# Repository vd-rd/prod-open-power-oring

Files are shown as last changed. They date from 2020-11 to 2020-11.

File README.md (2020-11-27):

# PowerPath controller with HotSwap protection

This module is designed to provide redundant power supply for power rails between 5-36V. Depending on the components that are populated on the board it can deliver up to 40A of current. The module can be used in a standalone configuration (switches are provided to select desired functionality) or can be controlled using the 2.54 pin header.

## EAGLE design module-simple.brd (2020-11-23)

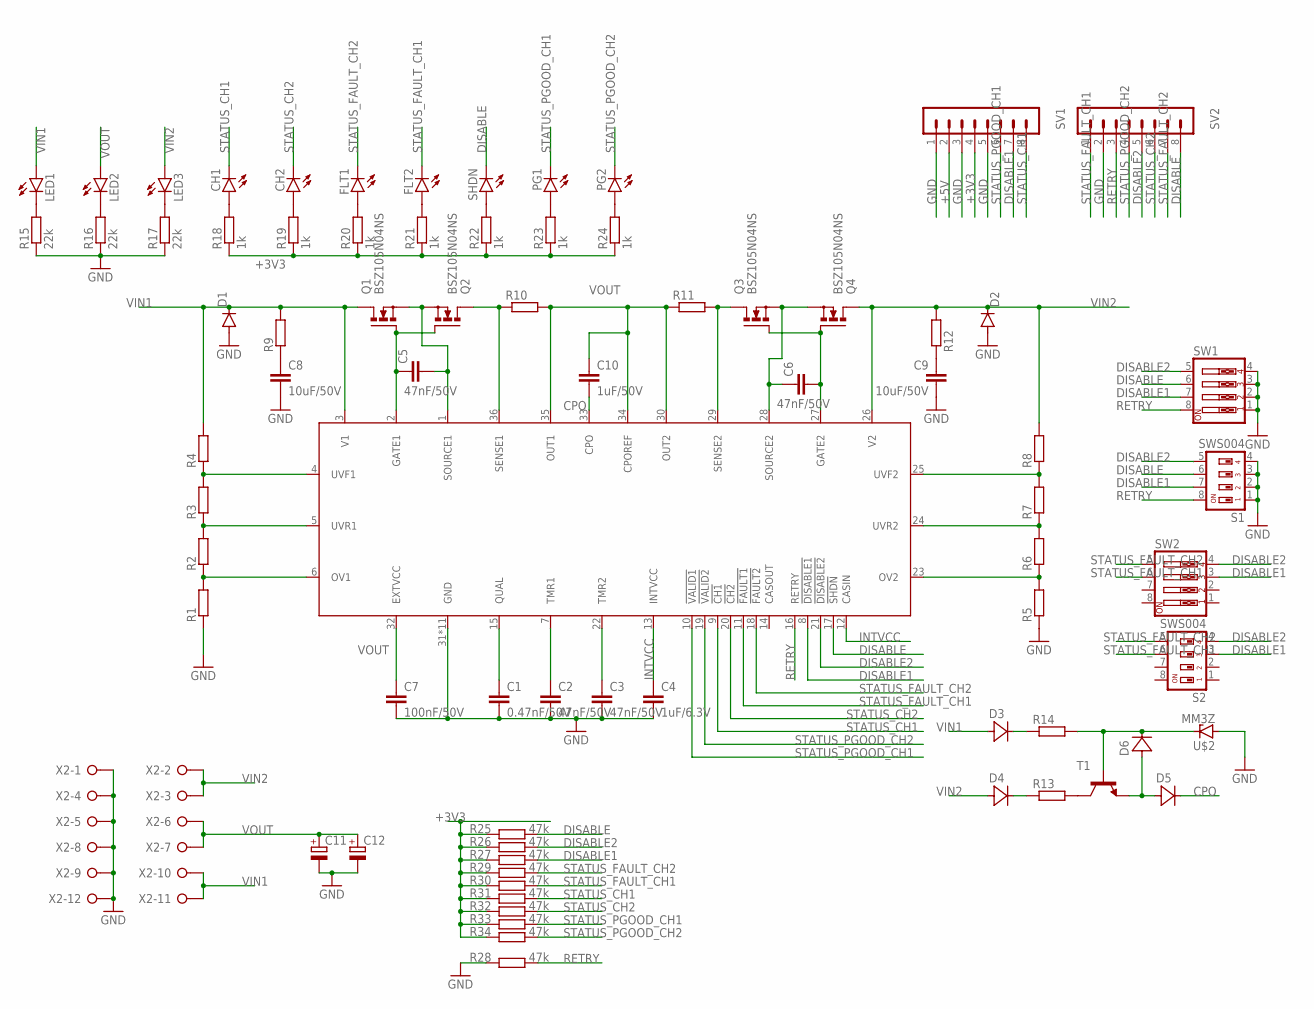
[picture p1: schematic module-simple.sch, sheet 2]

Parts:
C1: 0.47nF/50V; C0603
C2, C3, C5, C6: 47nF/50V; C0603
C4: 1uF/6.3V; C0603
C7: 100nF/50V; C0603
C8, C9: 10uF/50V; C1206
C10: 1uF/50V; C0805
C11, C12: CPOL-EU140CLH-1010; 140CLH-1010
CH1, CH2: LEDCHIP-LED0603; CHIP-LED0603
D1, D2: DIODE-DO214AC; DO214AC
D3, D4, D5, D6: 1N4148WS; SOD323
FLT1, FLT2: LEDCHIP-LED0603; CHIP-LED0603
LED1, LED2, LED3: LEDCHIP-LED0603; CHIP-LED0603
PG1, PG2: LEDCHIP-LED0603; CHIP-LED0603
Q1, Q2, Q3, Q4: BSZ105N04NS; PG-TDSON-8
R1, R2, R3, R4, R5, R6, R7, R8, R9, R12, R13, R14: R-EU_R0603; R0603
R10, R11: R-EU_R2512; R2512
R15, R16, R17: 22k; R0603
R18, R19, R20, R21, R22, R23, R24: 1k; R0603
R25, R26, R27, R28, R29, R30, R31, R32, R33, R34: 47k; R0603
S1, S2: SWS004; SMS-004
SHDN: LEDCHIP-LED0603; CHIP-LED0603
SV1, SV2: MA08-1
SW1, SW2: SW_DIP-4; EDG-04
T1: MMBT2222ALT1-NPN-SOT23-BEC; SOT23-BEC
U$1: LTC4421; QFN50P600X500X75-37T460X360N
U$2: MM3Z; SOD323
X2: W237-12P

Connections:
+3V3: R18.1, R19.1, R20.1, R21.1, R22.1, R23.1, R24.1, R25.1, R26.1, R27.1, R29.1, R30.1, R31.1, R32.1, R33.1, R34.1, SV1.4; also elsewhere on the board
+5V: SV1.2; also elsewhere on the board
CPO: C10.2, D5.K (C), U$1.33 (CPO)
DISABLE: R25.2, S1.6, SHDN.C, SV2.8, SW1.6, U$1.17 (!SHDN)
DISABLE1: R27.2, S1.7, S2.3, SV1.7, SW1.7, SW2.3, U$1.8 (!DISABLE1)
DISABLE2: R26.2, S1.5, S2.4, SV2.5, SW1.5, SW2.4, U$1.21 (!DISABLE2)
GND: C1.2, C2.2, C3.2, C4.2, C7.2, C8.2, C9.2, C11.-, C12.-, D1.A, D2.A, R1.1, R5.1, R15.1, R16.1, R17.1, R28.1, S1.1, S1.2, S1.3, S1.4, SV1.1, SV1.3, SV1.5, SV2.2, SW1.1, SW1.2, SW1.3, SW1.4, U$1.31 (GND), U$1.37 (GND), U$1.P$1 (GND), U$1.P$2 (GND), U$1.P$3 (GND), U$1.P$4 (GND), U$1.P$5 (GND), U$1.P$6 (GND), U$1.P$7 (GND), U$1.P$8 (GND), U$1.P$9 (GND), U$2.A, X2.1, X2.4, X2.5, X2.8, X2.9, X2.12; also elsewhere on the board
INTVCC: C4.1, U$1.12 (CASIN), U$1.13 (INTVCC)
unnamed: R1.2, R2.1, U$1.6 (OV1)
unnamed: R2.2, R3.1, U$1.5 (UVR1)
unnamed: R3.2, R4.1, U$1.4 (UVF1)
unnamed: R5.2, R6.1, U$1.23 (OV2)
unnamed: R6.2, R7.1, U$1.24 (UVR2)
unnamed: R7.2, R8.1, U$1.25 (UVF2)
unnamed: C5.1, Q1.4 (G), Q2.4 (G), U$1.2 (GATE1)
unnamed: C5.2, Q1.1 (S), Q1.2 (S), Q1.3 (S), Q2.1 (S), Q2.2 (S), Q2.3 (S), U$1.1 (SOURCE1)
unnamed: Q2.5 (D), Q2.6 (D), Q2.7 (D), Q2.8 (D), Q2.TH (D), R10.1, U$1.36 (SENSE1)
unnamed: C8.1, R9.1
unnamed: C9.1, R12.1
unnamed: D4.K (C), R13.1
unnamed: C1.1, U$1.15 (QUAL)
unnamed: Q3.5 (D), Q3.6 (D), Q3.7 (D), Q3.8 (D), Q3.TH (D), R11.2, U$1.29 (SENSE2)
unnamed: C6.2, Q3.4 (G), Q4.4 (G), U$1.27 (GATE2)
unnamed: C6.1, Q3.1 (S), Q3.2 (S), Q3.3 (S), Q4.1 (S), Q4.2 (S), Q4.3 (S), U$1.28 (SOURCE2)
unnamed: D3.K (C), R14.1
unnamed: C2.1, U$1.7 (TMR1)
unnamed: C3.1, U$1.22 (TMR2)
unnamed: R13.2, T1.C
unnamed: D6.K (C), R14.2, T1.B, U$2.K
unnamed: D5.A, D6.A, T1.E
unnamed: LED1.C, R15.2
unnamed: LED2.C, R16.2
unnamed: LED3.C, R17.2
unnamed: CH1.A, R18.2
unnamed: CH2.A, R19.2
unnamed: FLT1.A, R20.2
unnamed: FLT2.A, R21.2
unnamed: R22.2, SHDN.A
unnamed: PG1.A, R23.2
unnamed: PG2.A, R24.2
RETRY: R28.2, S1.8, SV2.3, SW1.8, U$1.16 (RETRY)
STATUS_CH1: CH1.C, R31.2, SV1.8, U$1.9 (!CH1)
STATUS_CH2: CH2.C, R32.2, SV2.6, U$1.20 (!CH2)
STATUS_FAULT_CH1: FLT2.C, R30.2, S2.6, SV2.1, SW2.6, U$1.11 (!FAULT1)
STATUS_FAULT_CH2: FLT1.C, R29.2, S2.5, SV2.7, SW2.5, U$1.18 (!FAULT2)
STATUS_PGOOD_CH1: PG1.C, R33.2, SV1.6, U$1.10 (!VALID1)
STATUS_PGOOD_CH2: PG2.C, R34.2, SV2.4, U$1.19 (!VALID2)
VIN1: D1.C, D3.A, LED1.A, Q1.5 (D), Q1.6 (D), Q1.7 (D), Q1.8 (D), Q1.TH (D), R4.2, R9.2, U$1.3 (V1), X2.10, X2.11
VIN2: D2.C, D4.A, LED3.A, Q4.5 (D), Q4.6 (D), Q4.7 (D), Q4.8 (D), Q4.TH (D), R8.2, R12.2, U$1.26 (V2), X2.2, X2.3
VOUT: C7.1, C10.1, C11.+, C12.+, LED2.A, R10.2, R11.1, U$1.30 (OUT2), U$1.32 (EXTVCC), U$1.34 (CPOREF), U$1.35 (OUT1), X2.6, X2.7; also elsewhere on the board

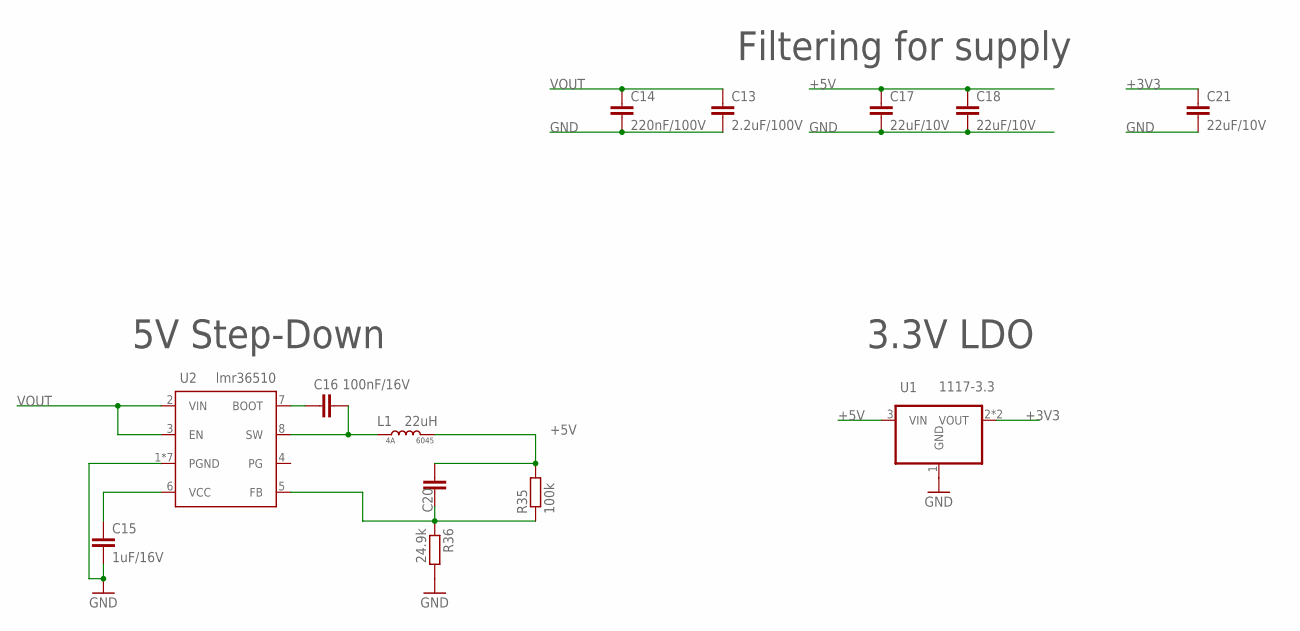
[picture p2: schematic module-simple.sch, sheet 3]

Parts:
C13: 2.2uF/100V; C1210
C14: 220nF/100V; C1210
C15: 1uF/16V; C0805
C16: 100nF/16V; C0805
C17, C18, C21: 22uF/10V; C1210
C20: C-EUC0603; C0603
L1: 22uH; DJNR6045
R35: 100k; R0603
R36: 24.9k; R0603
U1: 1117-3.3; SOT230P700X180-4
U2: lmr36510; SOIC127P600X170-9T240X310N

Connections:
+3V3: C21.1, U1.2 (VOUT), U1.4 (VOUT); also elsewhere on the board
+5V: C17.1, C18.1, C20.2, L1.P$2 (2), R35.2, U1.3 (VIN); also elsewhere on the board
GND: C13.2, C14.2, C15.2, C17.2, C18.2, C21.2, R36.2, U1.1 (GND), U2.1 (PGND), U2.9 (PGND), U2.P$1 (PGND), U2.P$2 (PGND), U2.P$3 (PGND), U2.P$4 (PGND), U2.P$5 (PGND); also elsewhere on the board
unnamed: C15.1, U2.6 (VCC)
unnamed: C16.1, U2.7 (BOOT)
unnamed: C16.2, L1.P$1 (1), U2.8 (SW)
unnamed: C20.1, R35.1, R36.1, U2.5 (FB)
VOUT: C13.1, C14.1, U2.2 (VIN), U2.3 (EN); also elsewhere on the board

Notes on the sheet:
5V Step-Down
3.3V LDO
Filtering for supply

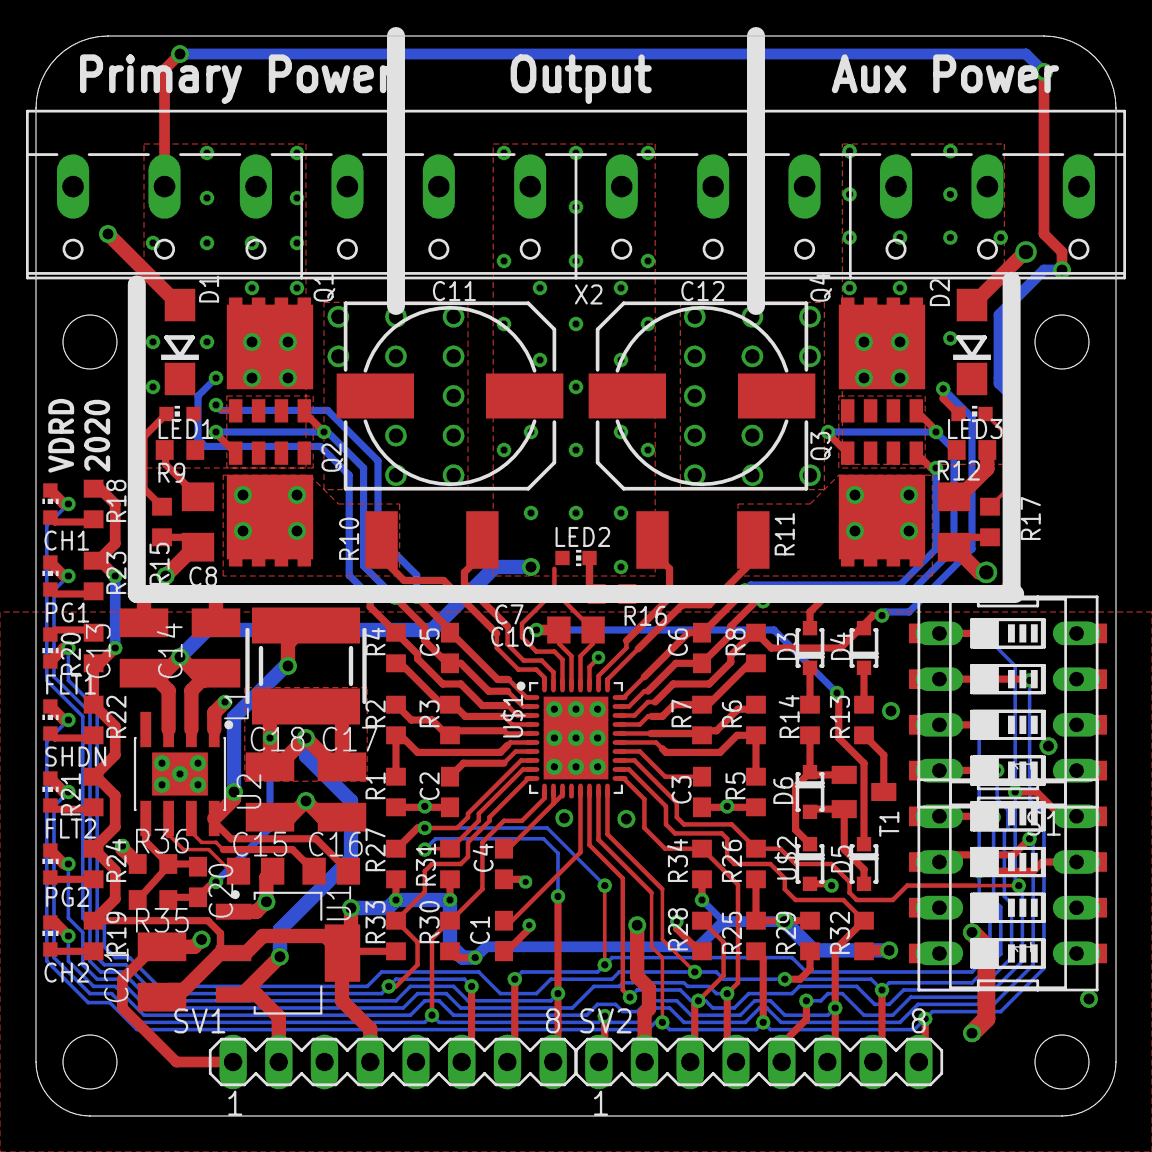
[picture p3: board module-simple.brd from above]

Board: 2 copper layers, 60.0 x 60.0 mm, 89 parts (0 on the bottom side), 54 nets.

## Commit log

2020-11-21 project: initial floorplan
    [module.brd, module.sch]
2020-11-21 project: define i/o
    [module.brd, module.sch]
2020-11-22 project: add demoboard module
    [module-simple.brd, module-simple.sch]
2020-11-23 project: finish features
    [module-simple.brd, module-simple.sch]
2020-11-23 project: run drc and cosmetic fixes
    [module-simple.brd, module-simple.sch]
